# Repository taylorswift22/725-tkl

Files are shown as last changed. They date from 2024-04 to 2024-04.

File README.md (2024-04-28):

725-tkl

DSC03376 - Copy

If you intend to have this produced, please contact me on discord "tamsin." because there are some small adjustments I should make.

DSC03377 - Copy




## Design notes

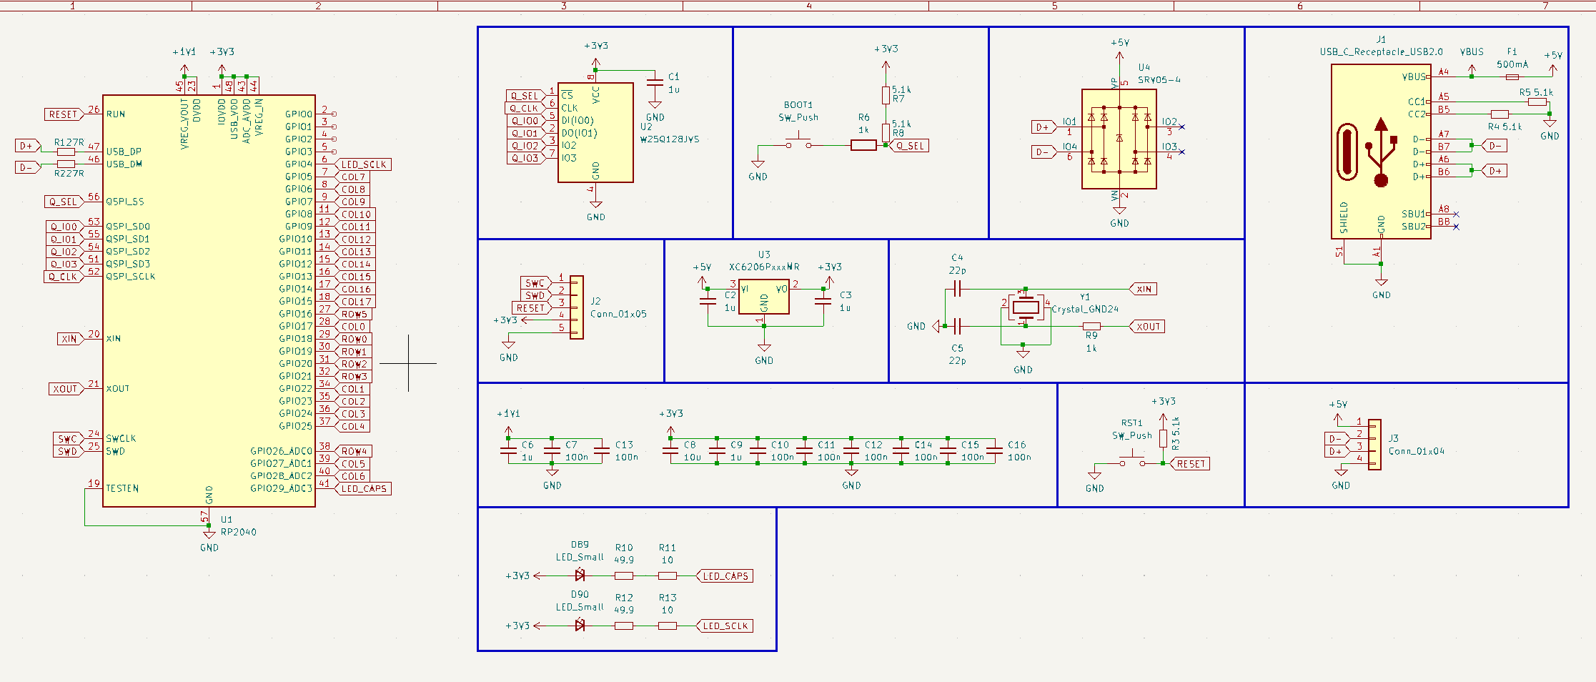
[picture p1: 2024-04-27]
PCB/Pictures/Progress Review.png

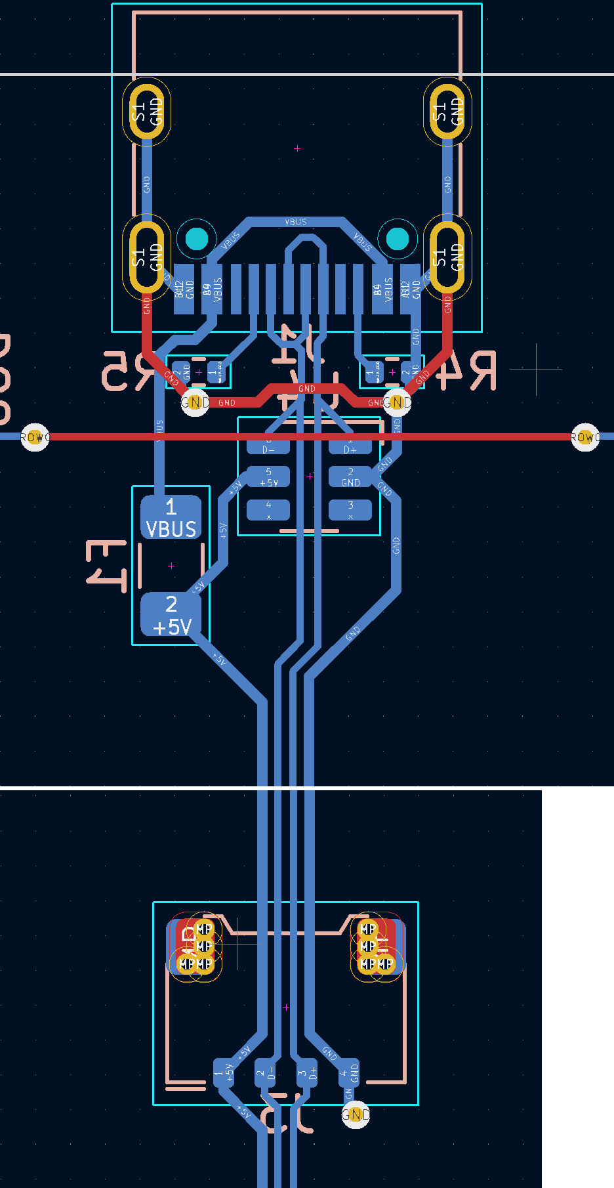
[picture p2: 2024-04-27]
PCB/Pictures/Progress_Review_3.png

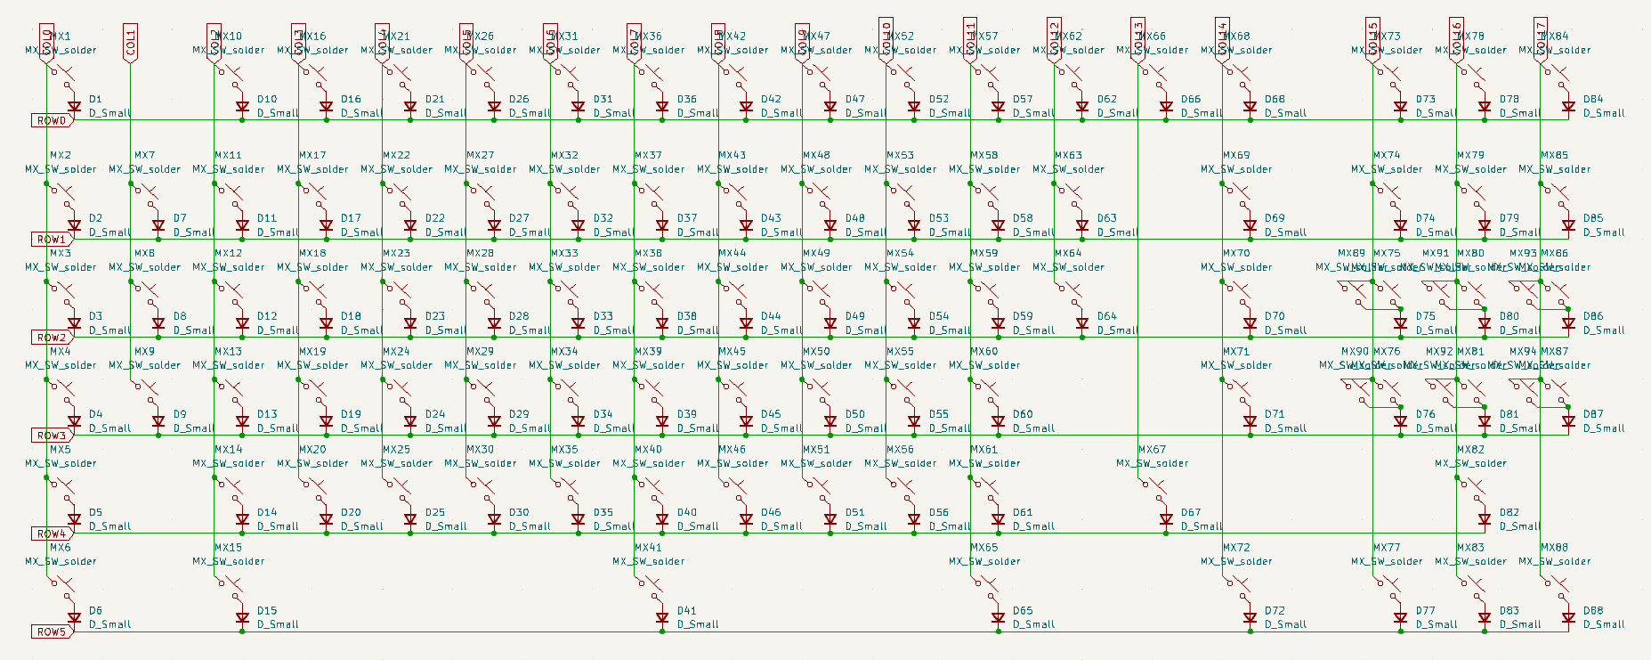
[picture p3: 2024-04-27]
PCB/Pictures/Progress_Review_5.png

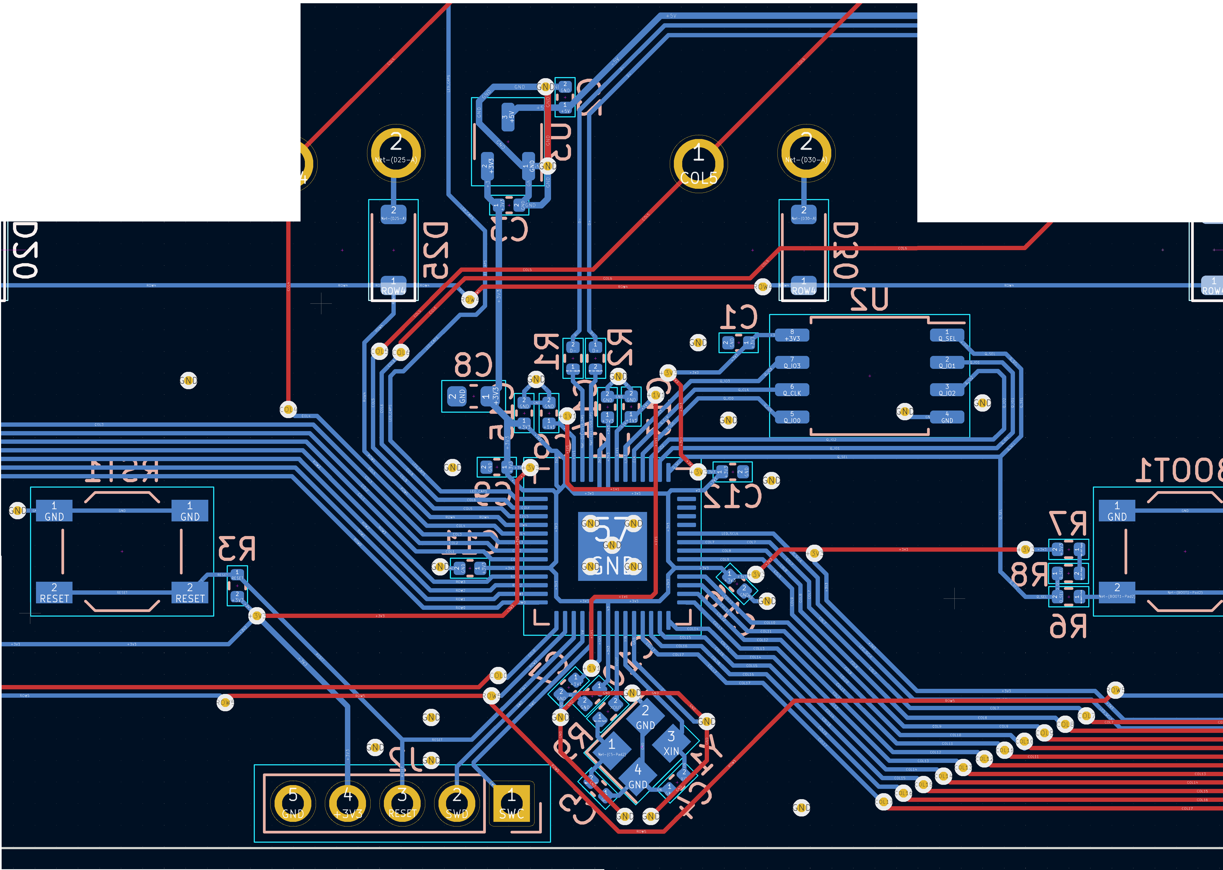
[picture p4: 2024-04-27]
PCB/Pictures/Progress_Review_2.png

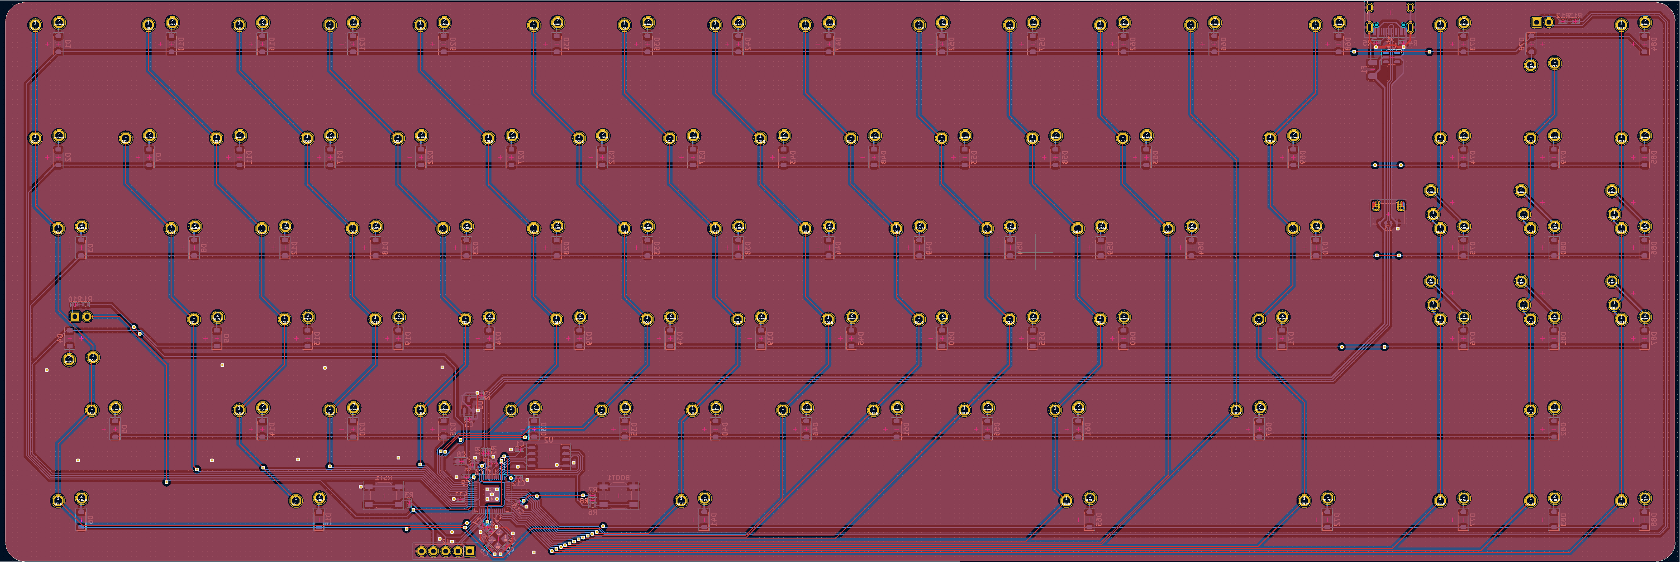
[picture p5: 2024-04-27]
PCB/Pictures/PCB_Review_4.png

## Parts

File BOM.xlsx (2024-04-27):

Item | Quantity | Note | Link
M2x0.4x8mm Mcmaster-carr 18-8 Stainless Steel Low-Profile Socket Head Screws | 10 | Case Screws | https://www.mcmaster.com/92855A839
M2x0.4x6mm Mcmaster-carr 18-8 Stainless Steel Socket Head Screw | 10 | Plate Screws | https://www.mcmaster.com/91292A831
M2x0.4x3mm Mcmaster-carr 18-8 Stainless Steel Socket Head Screw | 2 | UDB Screws | https://www.mcmaster.com/91292A003
M5x0.8x5mm McMaster-carr 18-8 Stainless Steel Low-Profile Socket Head Screws | 2 | Weight Screws | https://www.mcmaster.com/90666A119/
UDB-S1 | 1 | Daughterboard - link includes cable | https://cannonkeys.com/products/unified-daughterboard-and-jst-cable?variant=41613867843695
Plate | 1 | 1.2mm
Top Case | 1
Bottom Case | 1
Weight | 1
PCB | 1

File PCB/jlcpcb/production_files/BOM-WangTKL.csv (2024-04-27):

Comment | Designator | Footprint | LCSC
1k | R6,R9 | R_0402_1005Metric | C11702
W25Q128JVS | U2 | SOIC-8_5.23x5.23mm_P1.27mm | C131025
27R | R1,R2 | R_0402_1005Metric | C138021
22p | C4,C5 | C_0402_1005Metric | C1555
10u | C8 | C_0603_1608Metric | C19702
RP2040 | U1 | QFN-56-1EP_7x7mm_P0.4mm_EP3.2x3.2mm | C2040
120 | R10,R12 | R_0402_1005Metric | C25079
5.1k | R3,R4,R5,R7,R8 | R_0402_1005Metric | C25905
100n | C10,C11,C12,C13,C14,C15,C16,C7 | C_0402_1005Metric | C307331
SW_Push | BOOT1,RST1 | SW_SPST_TL3342 | C318884
Conn_01x04 | J3 | Molex_Pico-EZmate_78171-0004_1x04-1MP_P1.20mm_Vertical | C528030
1u | C1,C2,C3,C6,C9 | C_0402_1005Metric | C52923
XC6206PxxxMR | U3 | SOT-23-3 | C5446
500mA | F1 | Fuse_1206_3216Metric | C70076
D_Small | D1,D10,D11,D12,D13,D14,D15,D16,D17,D18,D19,D2,D20,D21,D22,D23,D24,D25,D26,D27,D28,D29,D3,D30,D31,D32,D33,D34,D35,D36,D37,D38,D39,D4,D40,D41,D42,D43,D44,D45,D46,D47,D48,D49,D5,D50,D51,D52,D53,D54,D55,D56,D57,D58,D59,D6,D60,D61,D62,D63,D64,D65,D66,D67,D68,D69,D7,D70,D71,D72,D73,D74,D75,D76,D77,D78,D79,D8,D80,D81,D82,D83,D84,D85,D86,D87,D88,D9 | D_SOD-123 | C81598
SRV05-4 | U4 | SOT-23-6-routable | C85364
Crystal_GND24 | Y1 | Crystal_SMD_3225-4Pin_3.2x2.5mm | C9002

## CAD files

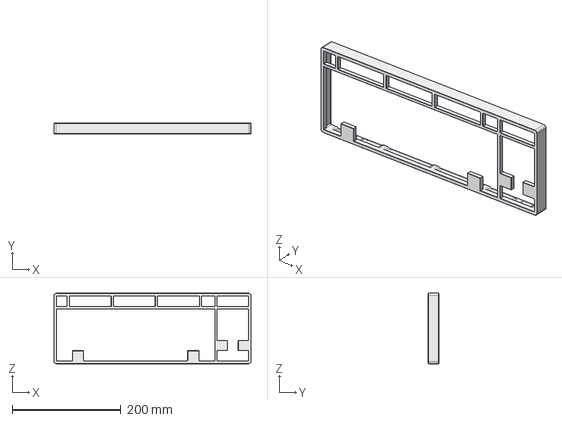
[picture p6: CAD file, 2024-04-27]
Case/TopCase.stp
361.9 x 19.5 x 129.6 mm

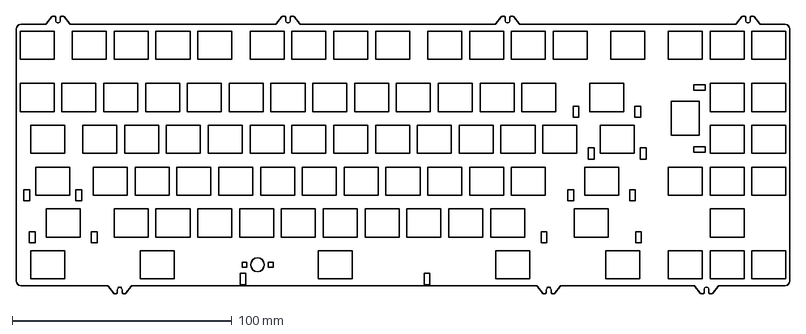
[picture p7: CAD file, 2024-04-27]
Plate/Plate.dxf
352.4 x 126.5 mm

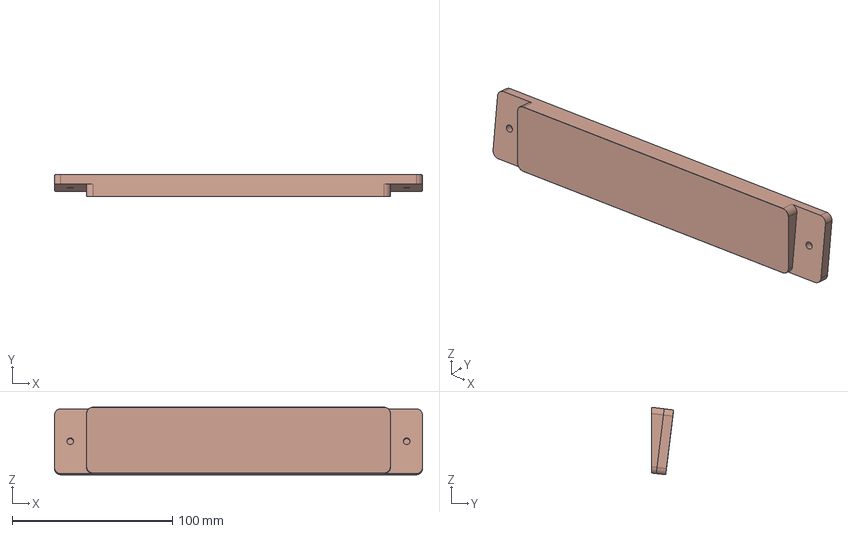
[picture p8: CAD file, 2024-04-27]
Case/Weight.stp
229.8 x 14.0 x 42.2 mm

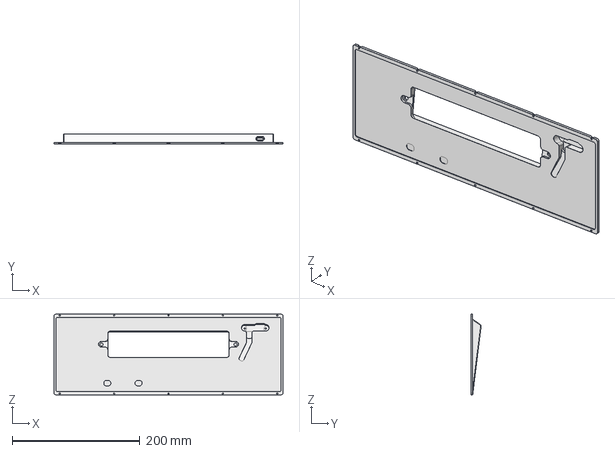
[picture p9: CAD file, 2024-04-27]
Case/BottomCase.stp
358.7 x 16.3 x 126.4 mm

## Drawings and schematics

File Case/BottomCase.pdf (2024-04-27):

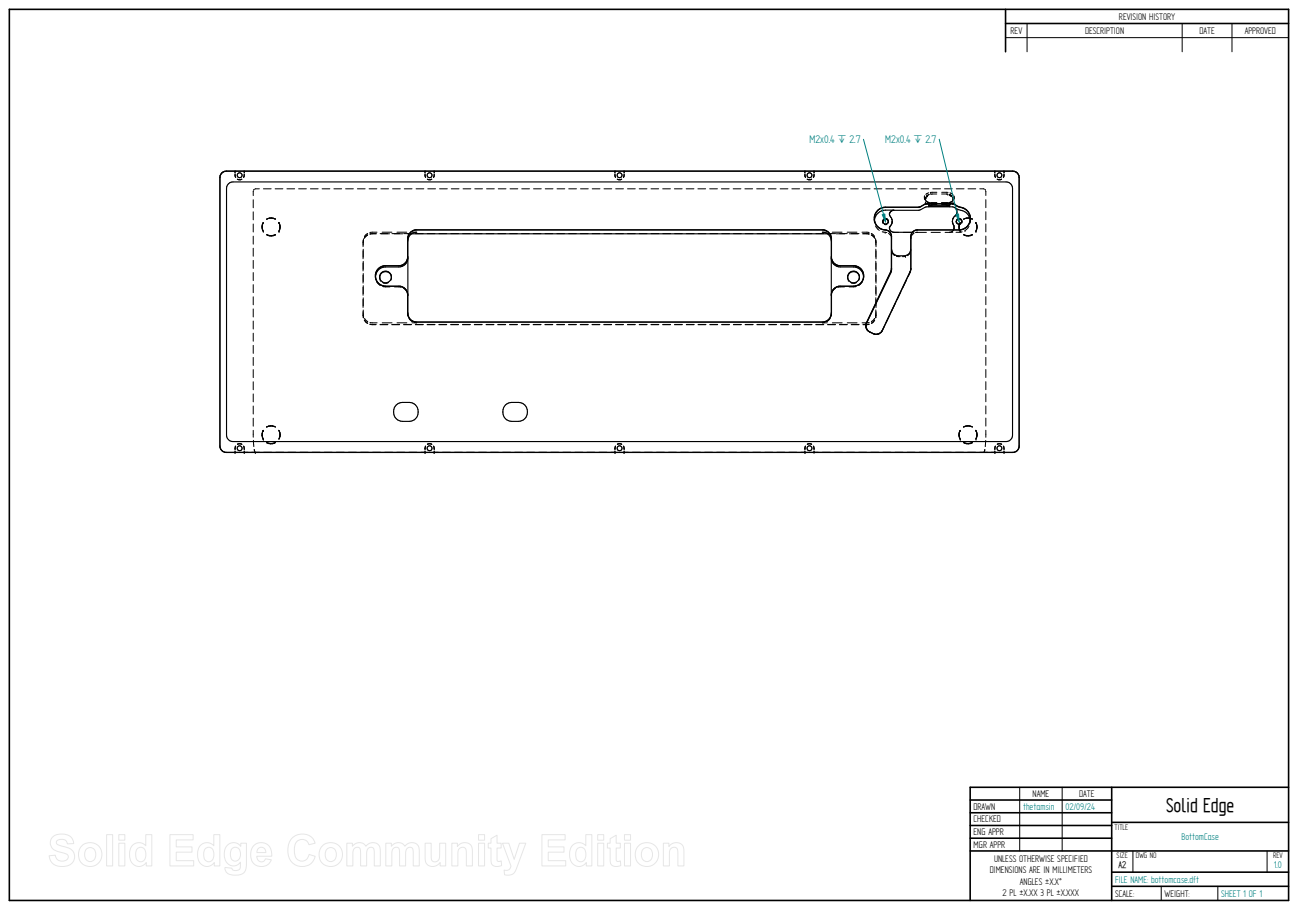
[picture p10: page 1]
TITLE; BottomCase; SCALE:; WEIGHT:; SHEET 1 OF 1

M2x0.4 ` 2.7 | REVISION HISTORY

REV | DESCRIPTION | DATE | APPROVED

NAME | DATE | Solid Edge

DRAWN | thetamsin | 02/09/24
CHECKED
ENG APPR
MGR APPR
UNLESS OTHERWISE SPECIFIED DIMENSIONS ARE IN MILLIMETERS ANGLES ±X.X° 2 PL ±X.XX 3 PL ±X.XXX | SIZE A2 | DWG NO | REV 1.0

FILE NAME: bottomcase.dft

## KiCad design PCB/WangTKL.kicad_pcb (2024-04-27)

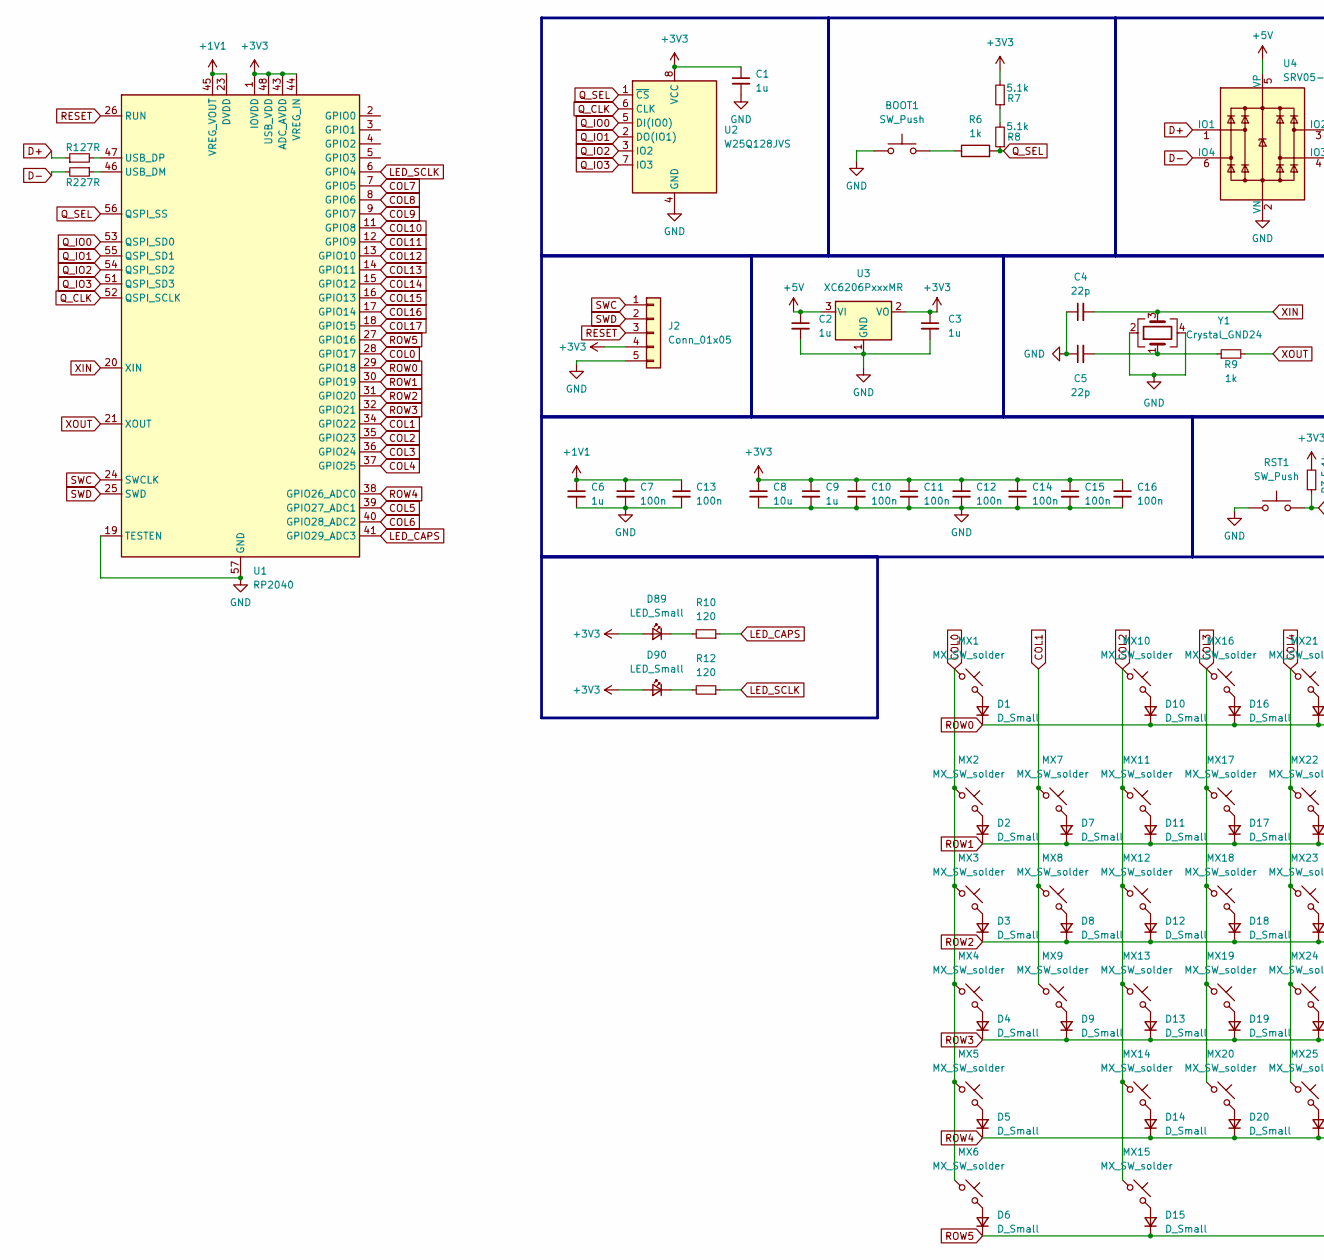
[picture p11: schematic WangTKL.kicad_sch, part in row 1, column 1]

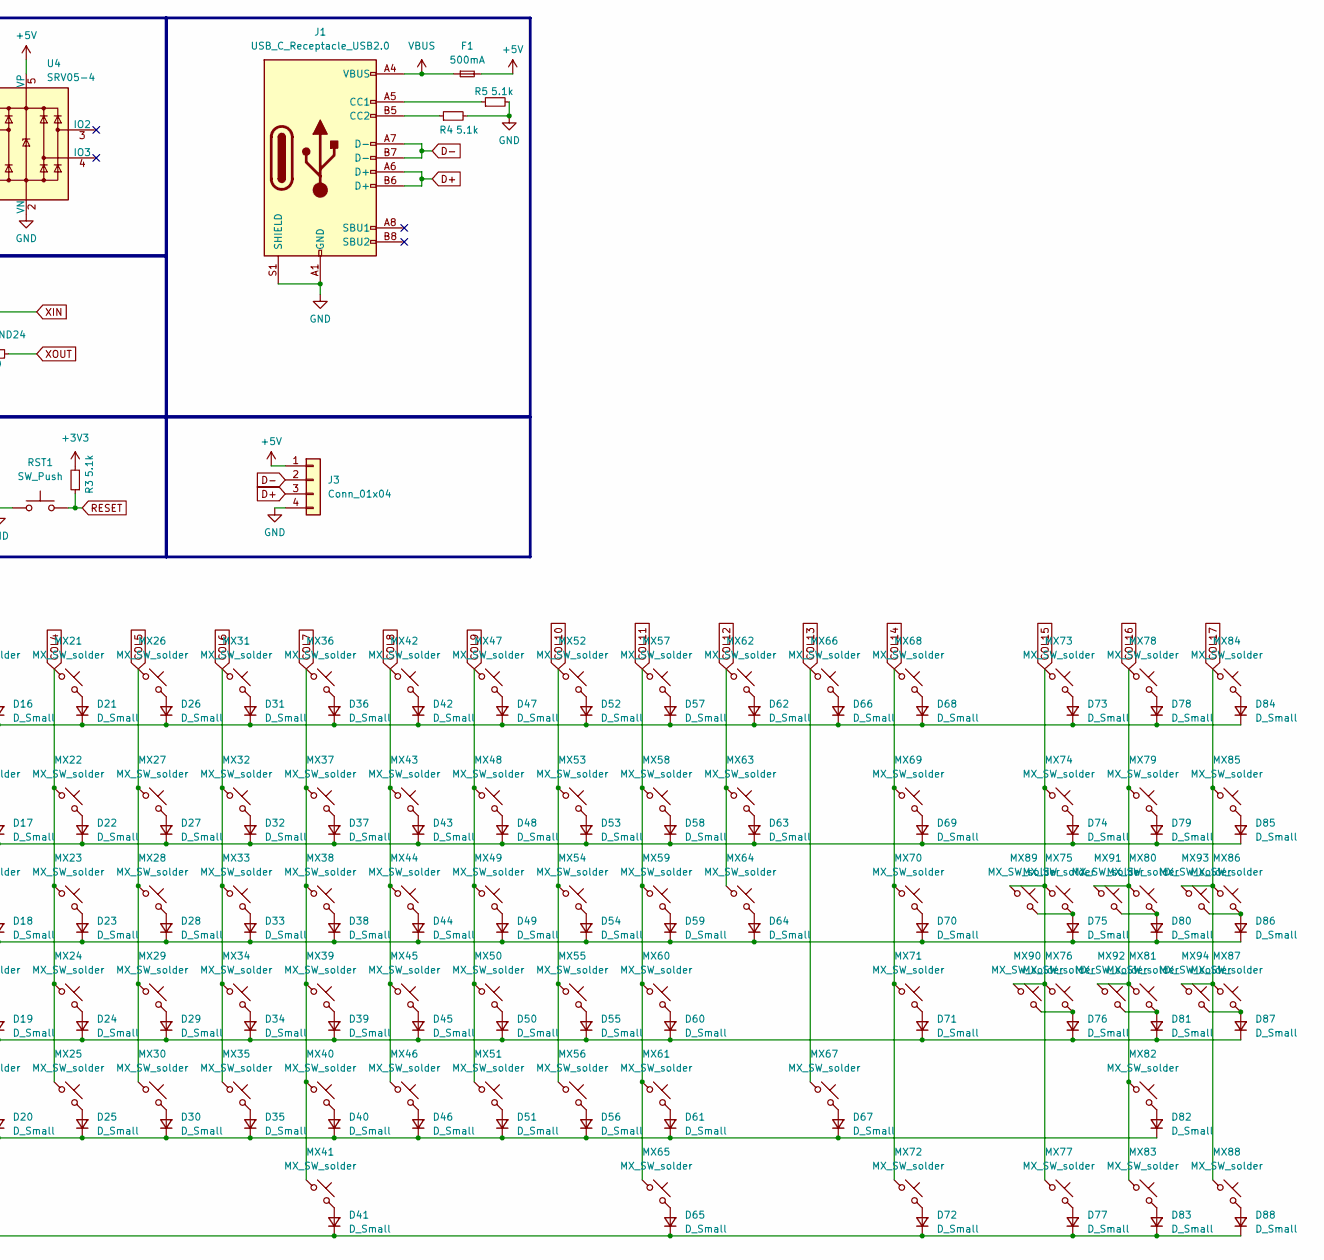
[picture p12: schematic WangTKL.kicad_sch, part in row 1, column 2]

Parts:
BOOT1: SW_Push; SW_SPST_TL3342
C1, C2, C3, C6, C9: 1u; C_0402_1005Metric
C4, C5: 22p; C_0402_1005Metric
C7, C10, C11, C12, C13, C14, C15, C16: 100n; C_0402_1005Metric
C8: 10u; C_0603_1608Metric
D1, D2, D3, D4, D5, D6, D7, D8, D9, D10, D11, D12, D13, D14, D15, D16, D17, D18, D19, D20, D21, D22, D23, D24, D25, D26, D27, D28, D29, D30, D31, D32, D33, D34, D35, D36, D37, D38, D39, D40, D41, D42, D43, D44, D45, D46, D47, D48, D49, D50, D51, D52, D53, D54, D55, D56, D57, D58, D59, D60, D61, D62, D63, D64, D65, D66, D67, D68, D69, D70, D71, D72, D73, D74, D75, D76, D77, D78, D79, D80, D81, D82, D83, D84, D85, D86, D87, D88: D_Small; D_SOD-123
D89, D90: LED_Small; PinHeader_1x02_P2.54mm_Horizontal
F1: 500mA; Fuse_1206_3216Metric
J1: USB_C_Receptacle_USB2.0; USB_C_Receptacle_HRO_TYPE-C-31-M-12
J2: Conn_01x05; PinHeader_1x05_P2.54mm_Vertical
J3: Conn_01x04; Molex_Pico-EZmate_78171-0004_1x04-1MP_P1.20mm_Vertical
MX1, MX2, MX3, MX4, MX5, MX6, MX7, MX8, MX9, MX10, MX11, MX12, MX13, MX14, MX15, MX16, MX17, MX18, MX19, MX20, MX21, MX22, MX23, MX24, MX25, MX26, MX27, MX28, MX29, MX30, MX31, MX32, MX33, MX34, MX35, MX36, MX37, MX38, MX39, MX40, MX41, MX42, MX43, MX44, MX45, MX46, MX47, MX48, MX49, MX50, MX51, MX52, MX53, MX54, MX55, MX56, MX57, MX58, MX59, MX60, MX61, MX62, MX63, MX64, MX65, MX66, MX67, MX68, MX69, MX70, MX71, MX72, MX73, MX74, MX75, MX76, MX77, MX78, MX79, MX80, MX81, MX82, MX83, MX84, MX85, MX86, MX87, MX88, MX89, MX90, MX91, MX92, MX93, MX94: MX_SW_solder; SW_Alps_1u
R1, R2: 27R; R_0402_1005Metric
R3, R4, R5, R7, R8: 5.1k; R_0402_1005Metric
R6, R9: 1k; R_0402_1005Metric
R10, R12: 120; R_0402_1005Metric
RST1: SW_Push; SW_SPST_TL3342
U1: RP2040; QFN-56-1EP_7x7mm_P0.4mm_EP3.2x3.2mm
U2: W25Q128JVS; SOIC-8_5.23x5.23mm_P1.27mm
U3: XC6206PxxxMR; SOT-23-3
U4: SRV05-4; SOT-23-6-routable
Y1: Crystal_GND24; Crystal_SMD_3225-4Pin_3.2x2.5mm

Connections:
+1V1: C6.1, C7.1, C13.1, U1.23 (DVDD), U1.45 (VREG_VOUT), U1.50 (DVDD)
+3V3: C1.1, C3.1, C8.1, C9.1, C10.1, C11.1, C12.1, C14.1, C15.1, C16.1, D89.2 (A), D90.2 (A), J2.4, R3.2, R7.2, U1.1 (IOVDD), U1.10 (IOVDD), U1.22 (IOVDD), U1.33 (IOVDD), U1.42 (IOVDD), U1.43 (ADC_AVDD), U1.44 (VREG_IN), U1.48 (USB_VDD), U1.49 (IOVDD), U2.8 (VCC), U3.2 (VO)
+5V: C2.1, F1.2, J3.1, U3.3 (VI), U4.5 (VP)
COL0: MX1.1, MX2.1, MX3.1, MX4.1, MX5.1, MX6.1, U1.28 (GPIO17)
COL1: MX7.1, MX8.1, MX9.1, U1.34 (GPIO22)
COL2: MX10.1, MX11.1, MX12.1, MX13.1, MX14.1, MX15.1, U1.35 (GPIO23)
COL3: MX16.1, MX17.1, MX18.1, MX19.1, MX20.1, U1.36 (GPIO24)
COL4: MX21.1, MX22.1, MX23.1, MX24.1, MX25.1, U1.37 (GPIO25)
COL5: MX26.1, MX27.1, MX28.1, MX29.1, MX30.1, U1.39 (GPIO27_ADC1)
COL6: MX31.1, MX32.1, MX33.1, MX34.1, MX35.1, U1.40 (GPIO28_ADC2)
COL7: MX36.1, MX37.1, MX38.1, MX39.1, MX40.1, MX41.1, U1.7 (GPIO5)
COL8: MX42.1, MX43.1, MX44.1, MX45.1, MX46.1, U1.8 (GPIO6)
COL9: MX47.1, MX48.1, MX49.1, MX50.1, MX51.1, U1.9 (GPIO7)
COL10: MX52.1, MX53.1, MX54.1, MX55.1, MX56.1, U1.11 (GPIO8)
COL11: MX57.1, MX58.1, MX59.1, MX60.1, MX61.1, MX65.1, U1.12 (GPIO9)
COL12: MX62.1, MX63.1, MX64.1, U1.13 (GPIO10)
COL13: MX66.1, MX67.1, U1.14 (GPIO11)
COL14: MX68.1, MX69.1, MX70.1, MX71.1, MX72.1, U1.15 (GPIO12)
COL15: MX73.1, MX74.1, MX75.1, MX76.1, MX77.1, MX89.1, MX90.1, U1.16 (GPIO13)
COL16: MX78.1, MX79.1, MX80.1, MX81.1, MX82.1, MX83.1, MX91.1, MX92.1, U1.17 (GPIO14)
COL17: MX84.1, MX85.1, MX86.1, MX87.1, MX88.1, MX93.1, MX94.1, U1.18 (GPIO15)
D+: J1.A6 (D+), J1.B6 (D+), J3.3, R1.1, U4.1 (IO1)
D-: J1.A7 (D-), J1.B7 (D-), J3.2, R2.2, U4.6 (IO4)
GND: BOOT1.1, C1.2, C2.2, C3.2, C4.1, C5.1, C6.2, C7.2, C8.2, C9.2, C10.2, C11.2, C12.2, C13.2, C14.2, C15.2, C16.2, J1.A1 (GND), J1.A12 (GND), J1.B1 (GND), J1.B12 (GND), J1.S1 (SHIELD), J2.5, J3.4, R4.2, R5.2, RST1.1, U1.19 (TESTEN), U1.57 (GND), U2.4 (GND), U3.1 (GND), U4.2 (VN), Y1.2, Y1.4
LED_CAPS: R10.1, U1.41 (GPIO29_ADC3)
LED_SCLK: R12.1, U1.6 (GPIO4)
unnamed: BOOT1.2, R6.1
unnamed: C5.2, R9.1, Y1.1
unnamed: D1.2 (A), MX1.2
unnamed: D2.2 (A), MX2.2
unnamed: D3.2 (A), MX3.2
unnamed: D4.2 (A), MX4.2
unnamed: D5.2 (A), MX5.2
unnamed: D6.2 (A), MX6.2
unnamed: D7.2 (A), MX7.2
unnamed: D8.2 (A), MX8.2
unnamed: D9.2 (A), MX9.2
unnamed: D10.2 (A), MX10.2
unnamed: D11.2 (A), MX11.2
unnamed: D12.2 (A), MX12.2
unnamed: D13.2 (A), MX13.2
unnamed: D14.2 (A), MX14.2
unnamed: D15.2 (A), MX15.2
unnamed: D16.2 (A), MX16.2
unnamed: D17.2 (A), MX17.2
unnamed: D18.2 (A), MX18.2
unnamed: D19.2 (A), MX19.2
unnamed: D20.2 (A), MX20.2
unnamed: D21.2 (A), MX21.2
unnamed: D22.2 (A), MX22.2
unnamed: D23.2 (A), MX23.2
unnamed: D24.2 (A), MX24.2
unnamed: D25.2 (A), MX25.2
unnamed: D26.2 (A), MX26.2
unnamed: D27.2 (A), MX27.2
unnamed: D28.2 (A), MX28.2
unnamed: D29.2 (A), MX29.2
unnamed: D30.2 (A), MX30.2
unnamed: D31.2 (A), MX31.2
unnamed: D32.2 (A), MX32.2
unnamed: D33.2 (A), MX33.2
unnamed: D34.2 (A), MX34.2
unnamed: D35.2 (A), MX35.2
unnamed: D36.2 (A), MX36.2
unnamed: D37.2 (A), MX37.2
unnamed: D38.2 (A), MX38.2
unnamed: D39.2 (A), MX39.2
unnamed: D40.2 (A), MX40.2
unnamed: D41.2 (A), MX41.2
unnamed: D42.2 (A), MX42.2
unnamed: D43.2 (A), MX43.2
unnamed: D44.2 (A), MX44.2
unnamed: D45.2 (A), MX45.2
unnamed: D46.2 (A), MX46.2
unnamed: D47.2 (A), MX47.2
unnamed: D48.2 (A), MX48.2
unnamed: D49.2 (A), MX49.2
unnamed: D50.2 (A), MX50.2
unnamed: D51.2 (A), MX51.2
unnamed: D52.2 (A), MX52.2
unnamed: D53.2 (A), MX53.2
unnamed: D54.2 (A), MX54.2
unnamed: D55.2 (A), MX55.2
unnamed: D56.2 (A), MX56.2
unnamed: D57.2 (A), MX57.2
unnamed: D58.2 (A), MX58.2
unnamed: D59.2 (A), MX59.2
unnamed: D60.2 (A), MX60.2
unnamed: D61.2 (A), MX61.2
unnamed: D62.2 (A), MX62.2
unnamed: D63.2 (A), MX63.2
unnamed: D64.2 (A), MX64.2
unnamed: D65.2 (A), MX65.2
unnamed: D66.2 (A), MX66.2
unnamed: D67.2 (A), MX67.2
unnamed: D68.2 (A), MX68.2
unnamed: D69.2 (A), MX69.2
unnamed: D70.2 (A), MX70.2
unnamed: D71.2 (A), MX71.2
unnamed: D72.2 (A), MX72.2
unnamed: D73.2 (A), MX73.2
unnamed: D74.2 (A), MX74.2
unnamed: D75.2 (A), MX75.2, MX89.2
unnamed: D76.2 (A), MX76.2, MX90.2
unnamed: D77.2 (A), MX77.2
unnamed: D78.2 (A), MX78.2
unnamed: D79.2 (A), MX79.2
unnamed: D80.2 (A), MX80.2, MX91.2
unnamed: D81.2 (A), MX81.2, MX92.2
unnamed: D82.2 (A), MX82.2
unnamed: D83.2 (A), MX83.2
unnamed: D84.2 (A), MX84.2
unnamed: D85.2 (A), MX85.2
unnamed: D86.2 (A), MX86.2, MX93.2
unnamed: D87.2 (A), MX87.2, MX94.2
unnamed: D88.2 (A), MX88.2
unnamed: D89.1 (K), R10.2
unnamed: D90.1 (K), R12.2
unnamed: J1.A5 (CC1), R5.1
unnamed: J1.B5 (CC2), R4.1
unnamed: R7.1, R8.2
unnamed: R2.1, U1.46 (USB_DM)
unnamed: R1.2, U1.47 (USB_DP)
Q_CLK: U1.52 (QSPI_SCLK), U2.6 (CLK)
Q_IO0: U1.53 (QSPI_SD0), U2.5 (DI(IO0))
Q_IO1: U1.55 (QSPI_SD1), U2.2 (DO(IO1))
Q_IO2: U1.54 (QSPI_SD2), U2.3 (IO2)
Q_IO3: U1.51 (QSPI_SD3), U2.7 (IO3)
Q_SEL: R6.2, R8.1, U1.56 (QSPI_SS), U2.1 (~CS)
RESET: J2.3, R3.1, RST1.2, U1.26 (RUN)
ROW0: D1.1 (K), D10.1 (K), D16.1 (K), D21.1 (K), D26.1 (K), D31.1 (K), D36.1 (K), D42.1 (K), D47.1 (K), D52.1 (K), D57.1 (K), D62.1 (K), D66.1 (K), D68.1 (K), D73.1 (K), D78.1 (K), D84.1 (K), U1.29 (GPIO18)
ROW1: D2.1 (K), D7.1 (K), D11.1 (K), D17.1 (K), D22.1 (K), D27.1 (K), D32.1 (K), D37.1 (K), D43.1 (K), D48.1 (K), D53.1 (K), D58.1 (K), D63.1 (K), D69.1 (K), D74.1 (K), D79.1 (K), D85.1 (K), U1.30 (GPIO19)
ROW2: D3.1 (K), D8.1 (K), D12.1 (K), D18.1 (K), D23.1 (K), D28.1 (K), D33.1 (K), D38.1 (K), D44.1 (K), D49.1 (K), D54.1 (K), D59.1 (K), D64.1 (K), D70.1 (K), D75.1 (K), D80.1 (K), D86.1 (K), U1.31 (GPIO20)
ROW3: D4.1 (K), D9.1 (K), D13.1 (K), D19.1 (K), D24.1 (K), D29.1 (K), D34.1 (K), D39.1 (K), D45.1 (K), D50.1 (K), D55.1 (K), D60.1 (K), D71.1 (K), D76.1 (K), D81.1 (K), D87.1 (K), U1.32 (GPIO21)
ROW4: D5.1 (K), D14.1 (K), D20.1 (K), D25.1 (K), D30.1 (K), D35.1 (K), D40.1 (K), D46.1 (K), D51.1 (K), D56.1 (K), D61.1 (K), D67.1 (K), D82.1 (K), U1.38 (GPIO26_ADC0)
ROW5: D6.1 (K), D15.1 (K), D41.1 (K), D65.1 (K), D72.1 (K), D77.1 (K), D83.1 (K), D88.1 (K), U1.27 (GPIO16)
SWC: J2.1, U1.24 (SWCLK)
SWD: J2.2, U1.25 (SWD)
VBUS: F1.1, J1.A4 (VBUS), J1.A9 (VBUS), J1.B4 (VBUS), J1.B9 (VBUS)
XIN: C4.2, U1.20 (XIN), Y1.3
XOUT: R9.2, U1.21 (XOUT)

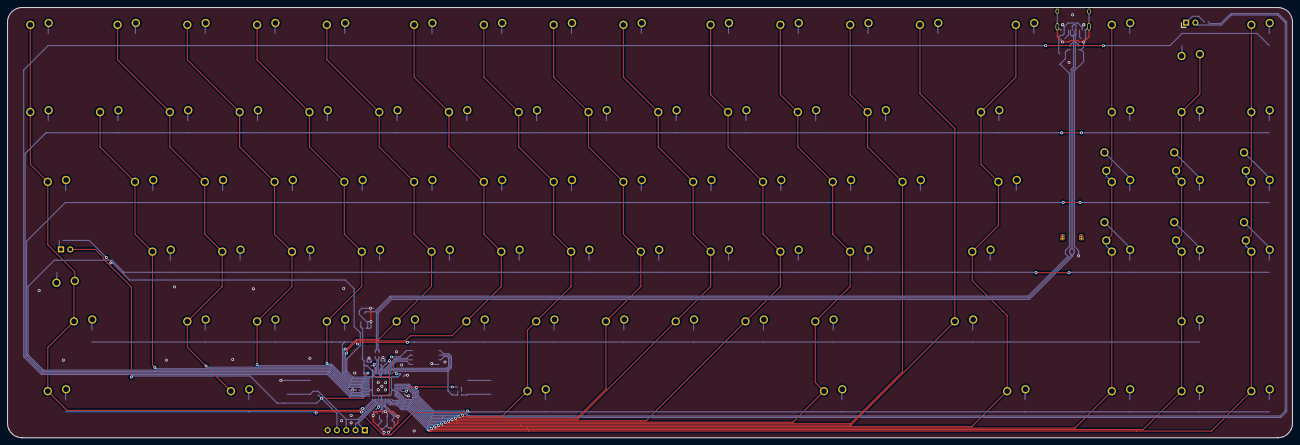
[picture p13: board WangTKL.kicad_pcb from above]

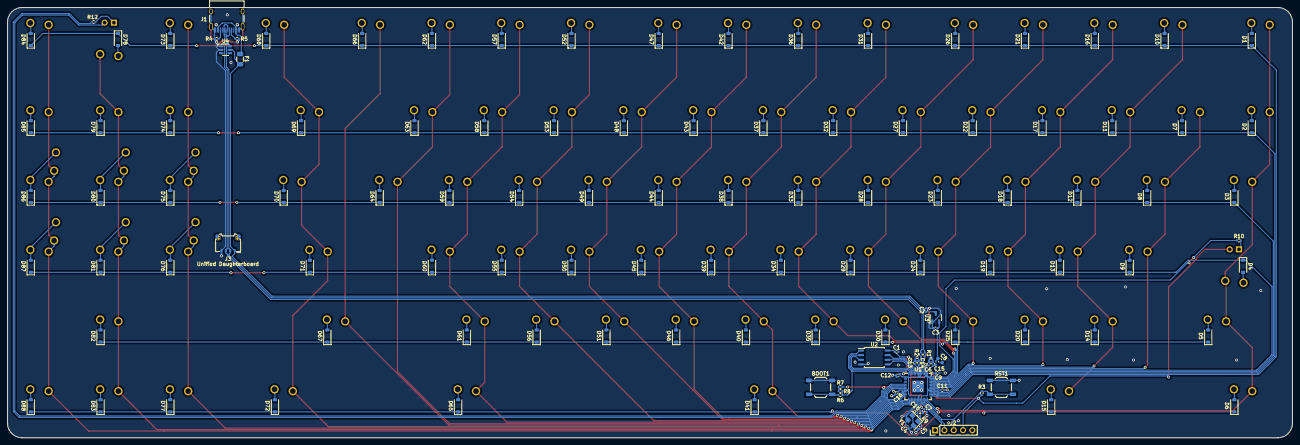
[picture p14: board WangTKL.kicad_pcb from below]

Board: 2 copper layers, 350.8 x 117.5 mm, 222 parts (126 on the bottom side), 141 nets.
